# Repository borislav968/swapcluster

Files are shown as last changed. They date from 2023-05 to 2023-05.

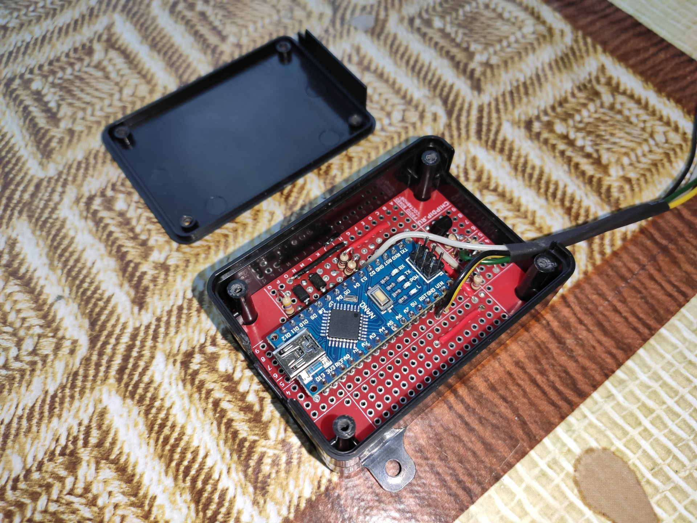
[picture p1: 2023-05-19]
hardware/device.jpg

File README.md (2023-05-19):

## Преобразователь частоты для автомобильного тахометра

Устройство предназначено для согласования частоты сигнала тахометра в случае её несоответствия - чаще всего, при замене двигателя на двигатель с иным числом цилиндров. Системы управления двигателей формируют сигнал для тахометра в соответствии с работой системы зажигания. Соотношение, в этом случае, соответствует половине числа цилиндров на один оборот двигателя - например, у 4-цилиндровых моторов это 2 импульса на оборот, у 6-цилиндровых - 3, и так далее.
Так как изменить заложенное в конструкцию тахометра (приборной панели) соотношение почти всегда сложно или невозможно, между ЭБУ двигателя и приборной панелью можно включить это устройство. Измеряя частоту сигнала на входе, оно формирует выходной сигнал другой частоты - в соответствии с настройками, которые следует сделать перед установкой на автомобиль (позже их также можно изменить).

Устройство презназначено только для низковольтных сигналов - с контактной системой зажигания и предназначенными для такой системы тахометрами оно работать не будет.

### Установка

Преобразователь следует установить недалеко от приборной панели, и подключить 4 провода:

- чёрный: масса
- жёлтый: питание 12В (15 контакт, при включенном зажигании)
- белый: входной сигнал (от ЭБУ двигателя, отсоединить провод от приборной панели)
- зелёный: выходной сигнал (к приборной панели вместо отсоединённого)

### Настройка

- Подключить к USB-порту компьютер с установленным драйвером последовательного порта CH341 и терминальной программой (например, Free Serial Terminal для Windows или minicom для Linux)
- настройки порта в терминальной программе: скорость 57600, 8 bit, 1 stop bit
- в окне терминала будут отображаться частота входного и выходного сигналов и предполагаемые обороты двигателя. Для настройки следует нажать "s".
- откроется экран настройки. Нажав "i" можно ввести число импульсов на один оборот для входного сигнала, а нажав "o" - изменить настройку для выходного сигнала.
- чтобы сохранить настройки, нужно нажать "q". Если настройки правильные, отображаемая в терминале скорость вращения должна соответствовать реальной, как и показания тахометра.

### Техническая информация

Первый вариант устройства основан на плате Arduino Nano с микроконтроллером ATMega328PB. Программа предназначена именно для этого типа контроллера, и с ATMega328P работать не будет.

### Контакты

E-mail: elgato@yavtanke.ru
YouTube: https://youtube.com/@flugegeheimen968
Telegram: https://t.me/ironcars5g

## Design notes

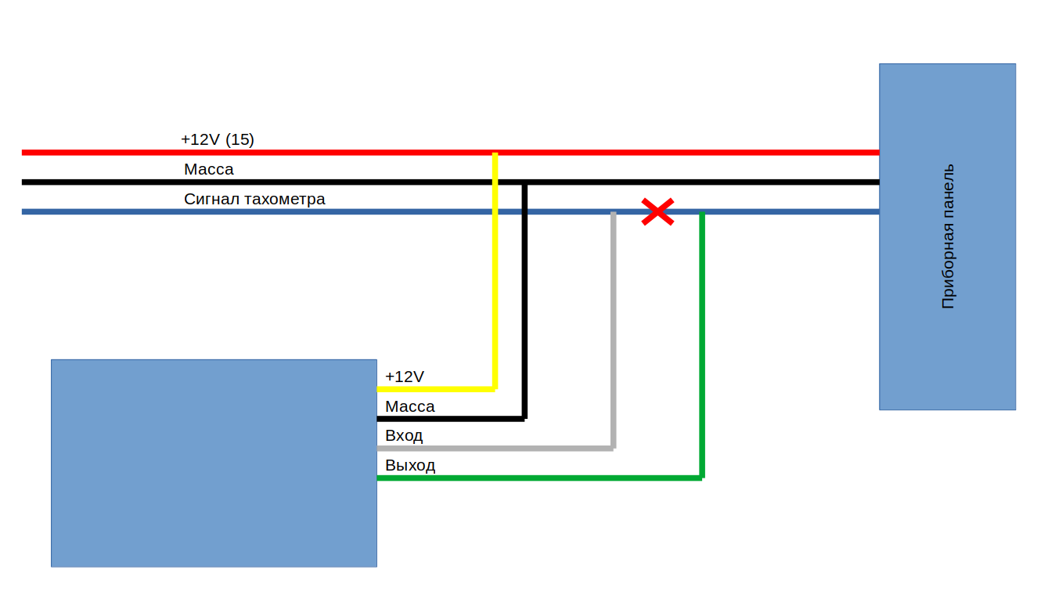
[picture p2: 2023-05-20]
hardware/connections.png

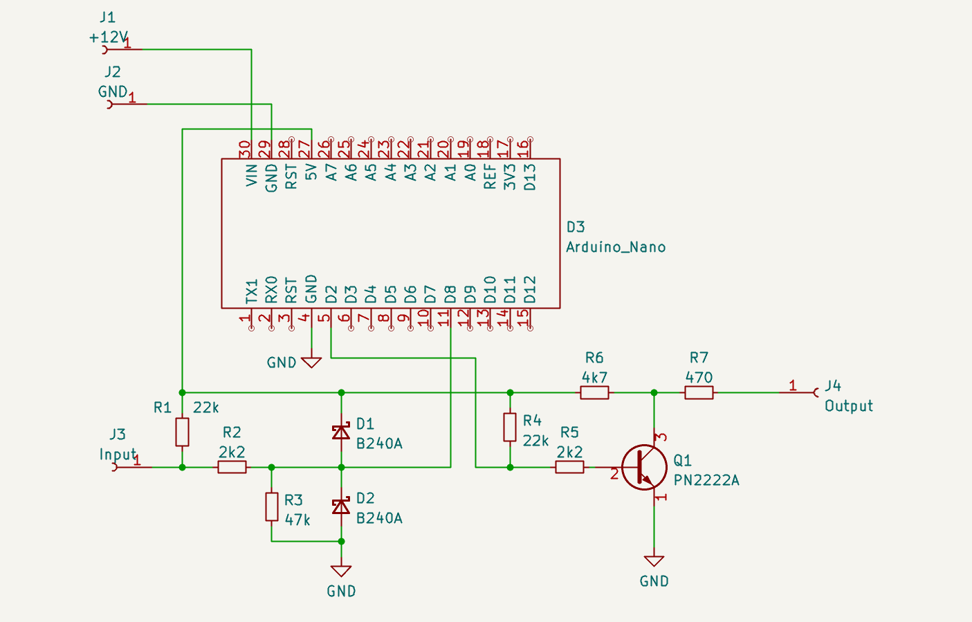
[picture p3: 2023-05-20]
hardware/circuit.png

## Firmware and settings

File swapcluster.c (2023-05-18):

#define F_CPU 16000000UL    // Тактовая частота 16МГц

#include <avr/io.h>
#include <avr/interrupt.h>
#include <avr/pgmspace.h>   // для вывода строк напрямую из flash-памяти
#include <avr/eeprom.h>     // для хранения настроек
#include <avr/wdt.h>        // сторожевой таймер
#include <stdio.h>          // для sprintf()

#define UART_BAUD_RATE 57600UL  // Скорость передачи UART 57600 бит/с
#define SET_UBRR ((F_CPU/(16UL*UART_BAUD_RATE))-1UL) // Значения регистров для настройки скорости UART


// Хранятся в EEPROM:
uint8_t EEMEM imp_in_E;         // число входных импульсов
uint8_t EEMEM imp_out_E;        // число выходных импульсов

// Используются при работе программы
uint8_t imp_in = 1;             // число входных импульсов
uint8_t imp_out = 1;            // число выходных импульсов

uint16_t period = UINT16_MAX;   // измеренный период сигнала в 1/62500с
uint8_t time = 0;               // используется в главном цикле
uint8_t setup_mode = 0;         // флаг режима настройки
char buffer [50];               // буфер для вывода строк в UART
char rxbuf = 0;                 // буфер приёма из UART

// Настроить UART
void init_uart () {
    UBRR0H = (uint8_t)(SET_UBRR>>8);        // настройка скорости
    UBRR0L = (uint8_t)SET_UBRR;
    UCSR0B |= (1<<TXEN0);                   // разрешение передачи
    UCSR0B |= (1<<RXEN0);                   // разрешение приёма
    UCSR0B |= (1<<RXCIE0);                  // включение прерывания по приёму
    UCSR0C |= (1<<UCSZ00) | (1<<UCSZ01);    // 8 бит
}

// Отправить символ в UART
void uart_putc (uint8_t data) {
    while (!(UCSR0A & (1<<UDRE0))); // ожидание готовности
    UDR0 = data;                    // отправка
}

// Отправить строку в UART
void uart_puts (char *s) {
    while (*s) {        // пока строка не закончилась
        uart_putc(*s);  // отправить очередной символ
        s++;            // передвинуть указатель на следующий символ
    }
}

// Отправить строку из памяти программ в UART
void uart_puts_P (const char *progmem_s) {
    register char c;
    while ((c = pgm_read_byte(progmem_s++))) {      // пока строка не закончилась
        uart_putc(c);                               // отправить очередной символ
    }
}

// принять символ из UART
char uart_getc () {
    while (!(UCSR0A & (1<<RXC0)));  // ожидание приёма
    return UDR0;                    // вернуть принятый байт
}

// Настроить таймер 1 (измерение частоты)
void init_meter () {
    TCCR1B |= (1<<ICES1);   // захват положительного фронта сигнала
    TIMSK1 |= (1<<ICIE1);   // включить прерывание по захвату
    TIMSK1 |= (1<<TOIE1);   // включить прерывание по переполнению
    TCCR1B |= (1<<CS12);    // делитель 256, частота 62500Гц
}

// Настроить таймер 3 (генератор выходного сигнала)
void init_gen () {
    DDRD |= (1<<PD2);           // сделать PD2 выходом
    PORTD |= (1<<PD2);          // для использования таймером, на этом выходе должна быть единица
    TCCR3A |= (1<<COM3B1);      // режим работы выхода OC3B: неинвертирующий
    // Режим работы таймера: Fast PWM со счётом до OCR3A, скважность в OCR3B
    TCCR3A |= (1<<WGM31) | (1<<WGM30);
    TCCR3B |= (1<<WGM33) | (1<<WGM32);
}

// Настроить таймер 4 (главный цикл)
void init_timer_main () {
    TCCR4B |= (1<<WGM42);   // режим сравнения
    OCR4A = 6250;           // отсчёт до 6250, 1/10с
    TIMSK4 |= (1<<OCIE4A);  // включить прерывание по сравнению
    TCCR4B |= (1<<CS42);    // делитель 256, частота 62500Гц
}

// Задать частоту генератора
void set_freq (uint16_t freq) {
    if (freq == 0) TCCR3B &= ~(1<<CS32);    // если заданная частота = 0, остановить генератор
    else {
        // Запустить генератор, если не запущен. Делитель 256, тактовая частота 62500Гц
        if (!(TCCR3B & 0b00000111)) TCCR3B |= (1<<CS32);
        OCR3A = (62500 / freq) - 1; // период импульсов в 62500-х долях секунды
        OCR3B = OCR3A / 2;          // для скважность 50% здесь половина от OCR3A
    }
}

// Прочитать настройки из EEPROM
void read_settings () {
    imp_in = eeprom_read_byte(&imp_in_E);
    if ((imp_in < 1) || (imp_in > 8)) imp_in = 1;
    imp_out = eeprom_read_byte(&imp_out_E);
    if ((imp_out < 1) || (imp_out > 8)) imp_out = 1;
    
}

// Прерывание по захвату сигнала таймером 1
ISR (TIMER1_CAPT_vect) {
    TCNT1 = 0;      // обнулить счётный регистр
    period = ICR1;  // результат измерения берётся из регистра захвата
}

// Прерывание по переполнению таймера 1
ISR (TIMER1_OVF_vect) {
    period = UINT16_MAX;
}

// Прерываение по сравнению таймера 4
ISR (TIMER4_COMPA_vect) {
    time++;
}

ISR (USART0_RX_vect) {
    if (UDR0 == 's') setup_mode++;
}

// Используется для настройки
void setup_pulses (uint8_t offset, uint8_t * setting) {
    register uint8_t correct = 0;
    sprintf(buffer, "\x1b[3A\x1b[%uC\x1b[?25h", offset);// переместить курсор в нужное место и показать его
    uart_puts(buffer);
    while (!correct) {                                  // повторять ожидание ввода, пока не будет введено допустимое значение
        rxbuf = uart_getc();                            // ожидание ввода
        if ((rxbuf >= 0x31) && (rxbuf <= 0x38)) {       // если введена цифра от 1 до 8
            *setting = rxbuf - 0x30;                    // присвоить переменной её значение
            correct++;                                  // завершить цикл
        }
    }
    uart_puts_P(PSTR("\x1b[?25l\r"));                   // спрятать курсор
}

int main () {
    
    MCUSR = 0;
    wdt_disable();

    uint16_t frequency = 0; // частота входного сигнала
    uint16_t freq_out = 0;  // частота на выходе
    uint16_t rpm = 0;       // обороты двигателя
    
    init_uart();        // настроить UART
    init_meter();       // настроить таймер 1 (измерение частоты)
    init_gen();         // настроить таймер 3 (генератор сигнала)
    init_timer_main();  // настроить таймер 4 (главный цикл)
    read_settings();
    
    uart_puts_P(PSTR("\x1b[2J\x1b[?25l\n\n"));
    uart_puts_P(PSTR("Преобразователь частоты тахометра\n\n\r"));
    uart_puts_P(PSTR("вход\tвыход\tоб/мин\n\n\n\r"));
    uart_puts_P(PSTR("Для настройки нажмите \"s\"\r\x1b[2A"));
    
    wdt_enable(WDTO_250MS);
    
    sei();  // разрешить все прерывания
   
    while (1) {
        if (time) {                                         // если прошло 100мс с прошлого выполнения
            wdt_reset();                                    // сбросить Watchdog
            frequency = 62500 / period;                     // вычислить частоту входного сигнала
            freq_out = (frequency / imp_in) * imp_out;      // ...выходного сигнала
            rpm = (frequency * 60) / imp_in;                // ...обороты двигателя
            set_freq(freq_out);                             // задать новую частоту генератору
            sprintf(buffer, "%u   \t%u   \t%u    \r", frequency, freq_out, rpm);    // вывести данные в терминал
            uart_puts(buffer);
            time = 0;                                       // обнуляется для правильной работы таймера
        }
        if (setup_mode) {                                   // режим настройки
            wdt_disable();                                  // Watchdog выключается
            set_freq(0);                                    // сигнал на выходе выключается
            cli();                                          // запрет всех прерываний
            uart_puts_P(PSTR("\x1b[2J\x1b[?25l\n\n"));
            uart_puts_P(PSTR("Настройка\x1b\r[6BСохранить и выйти: \"q\"\x1b[4A\r"));
            while (1) {
                sprintf(buffer, "Вход: %u имп/об, выход %u имп/об\n\n\r", imp_in, imp_out);
                uart_puts(buffer);
                uart_puts_P(PSTR("Изменить число импульсов: на входе \"i\", на выходе - \"o\"\n\r"));
                uart_puts_P(PSTR("Допустимые значения: от 1 до 8\r"));
                rxbuf = uart_getc();
                if (rxbuf == 'q') {                         // если нажата q
                    eeprom_write_byte(&imp_in_E, imp_in);   // сохранить настройки в EEPROM
                    eeprom_write_byte(&imp_out_E, imp_out);
                    wdt_enable(WDTO_500MS);                 // запустить Watchdog для перезагрузки
                    while (1) asm(" ");                     // ...и ждать его срабатывания
                } else if (rxbuf == 'i') {                  // если нажата i
                    setup_pulses(6, &imp_in);               // ждать ввода значения числа входных импульсов
                } else if (rxbuf == 'o') {                  // если нажата o
                    setup_pulses(22, &imp_out);             // ждать ввода значения числа выходных импульсов
                } else uart_puts_P(PSTR("\x1b[3A"));
            }
        }
        asm(" ");       // магия, без которой бесконечный цикл не работает
    }
    
}

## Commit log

2023-05-14 Add UART support
2023-05-16 Correct an error with frequency output
    [swapcluster.c]
2023-05-16 Solve zero frequency problem
    [swapcluster.c]
2023-05-18 Add UART receive
2023-05-18 Add comments and correct minor issues
    [swapcluster.c]
2023-05-18 Solve issue with settings screen layout
    [swapcluster.c]
2023-05-19 Add Readme, circuit diagram and a photo
2023-05-20 Bigger pull-up resistance at input
    [swapcluster.kicad_sch]
